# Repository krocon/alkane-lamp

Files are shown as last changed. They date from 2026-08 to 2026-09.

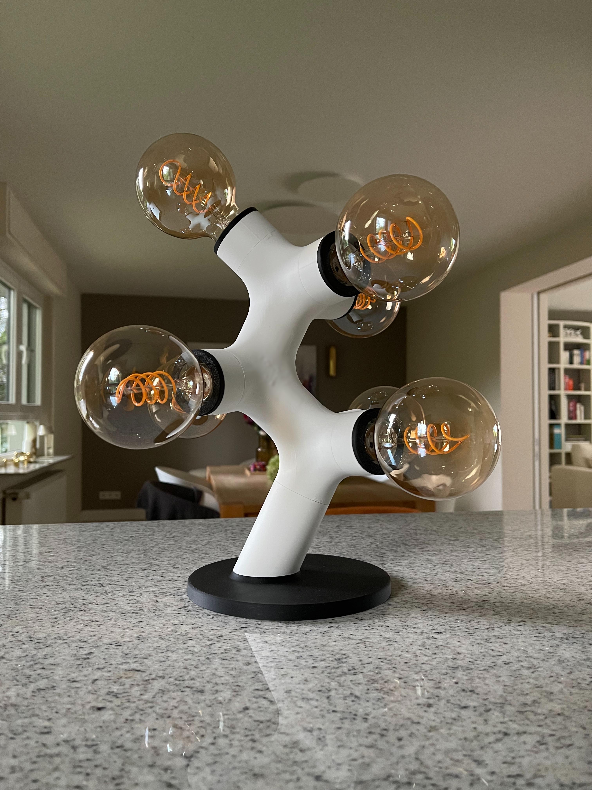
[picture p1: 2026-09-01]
picture/lamp-02.jpg

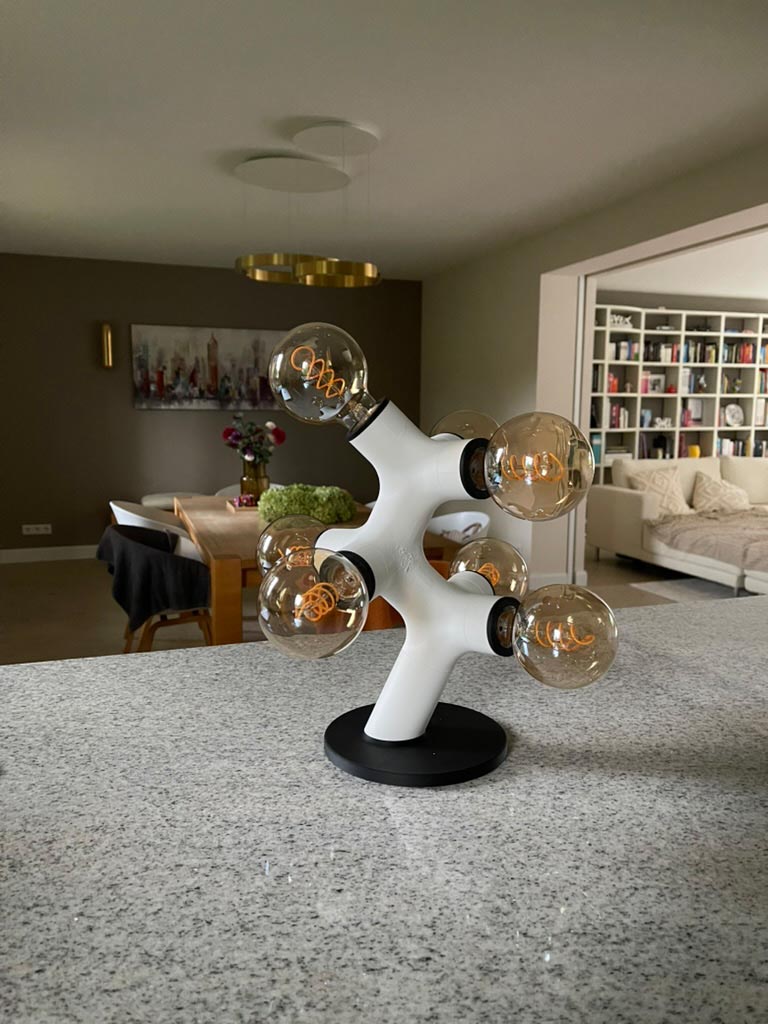
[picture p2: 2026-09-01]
picture/lamp-01.jpg

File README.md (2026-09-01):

# The Carbon Chain Chandelier

## The Alkane Modular Lamp System — Propane (C₃H₈) Edition

### A Scientifically Accurate, Modular Molecular Lighting System for 3D Printing






---

## Overview

Welcome to **The Carbon Chain Chandelier & Alkane Lamp System** — where organic chemistry meets modern Scandinavian sculptural lighting.

Inspired by iconic designer fixtures and molecular geometry, this project brings the fundamental building blocks of organic matter to life. Instead of arbitrary decorative shapes, every node, angle, and connection in this lamp is derived from **real covalent bonding geometry** (sp³ hybridization with the exact **109.47°** tetrahedral bond angle).

This first release features the **Propane (C₃H₈) Standing & Table Lamp**: a stunning 3-carbon backbone lamp with an integrated tilted base plate, hidden internal wiring channels, and modular socket connections.

It serves as the flagship model and the foundation for a **complete modular kit** — allowing you to expand from a single node to full organic chandeliers (**The Carbon Chain Chandelier** series), desk lamps, and sculptural floor installations.

---

## The Science Behind the Design

Alkanes are saturated hydrocarbons consisting entirely of single-bonded carbon and hydrogen atoms.

```
       H   H   H
       |   |   |
   H - C - C - C - H       Propane (C₃H₈)
       |   |   |
       H   H   H
```

### 1. Tetrahedral Carbon & sp³ Hybridization

In an alkane, each carbon atom undergoes sp³ hybridization, forming four equivalent covalent bonds directed toward the vertices of a regular tetrahedron. The mathematical bond angle is:

**θ = arccos(-1/3) ≈ 109.47°**

Every node in this lamp model strictly adheres to this 109.47° angle, giving it a natural, mathematically harmonious silhouette.

### 2. Staggered (Anti / Gauche) Conformation

Due to free rotation around the carbon-carbon (C-C) single σ-bonds, alkane chains naturally settle into a **staggered conformation**. This minimizes steric clash and torsional strain (Pitzer strain), resulting in the characteristic organic **zigzag backbone**. The Propane Lamp captures this exact 3D zigzag configuration in a self-balancing, visually captivating standing posture.

---

## Features & Highlights

- **True Modular Architecture:** Interchangeable tetrahedral carbon nodes, connector sleeves, weighted base plates, and socket adapters.
- **Internal Cable Routing:** Generous continuous hollow internal bores (Ø 43 mm) and an integrated base plate cable canal (Ø 7 mm with smooth chamfers) allow you to run standard electrical cables cleanly inside the lamp with zero exposed wires.
- **Self-Stabilizing Geometry:** The 160 mm base plate is tilted and counterbalanced to firmly support the 3-node propane structure with standard E27/E14 light fixtures and globes.
- **Optimized for FDM 3D Printing:** Designed to print with clean layer lines, robust wall thicknesses, and minimal/no unnecessary supports.
- **Standard Hardware Compatibility:** Designed for readily available E27 / E14 lamp sockets, Bambu LED Lamp Kits, or custom pendant cords.

---

## What's in the Kit?

The **Propane (C₃H₈) Starter Kit** includes all parametric parts required to build the complete standing lamp:

| Part Name | Description | Recommended Count |
| :--- | :--- | :---: |
| **`Node_1_Base`** | Tetrahedral Carbon Node 1 with integrated tilted foot stem | 1x |
| **`Node_2_Center`** | Tetrahedral Carbon Node 2 (central carbon backbone) | 1x |
| **`Node_3_Head`** | Tetrahedral Carbon Node 3 (top socket terminal) | 1x |
| **`Connector_Sleeves`** | Precision Ø 43 mm coupling sleeves with tolerance offset | 2x |
| **`Base_Plate_160mm`** | Heavy 160 mm circular base plate with rear cable outlet | 1x |
| **`Socket_Inlet_E27`** | Threaded / snap-in mount for standard E27 or E14 sockets | 1–3x (Optional) |
| **`M40_Locknut`** | Optional printed locknut for threaded modular joints | 1–3x |

> *Note: You can print the complete assembly in multi-piece modular format or as individual nodes depending on your build volume.*

---

## Bill of Materials (BOM) & Required Hardware

To complete the electrical build, you will need:

1. **Light Bulb Socket:**
   - 1x Standard **E27** (or **E14**) threaded socket with mounting collar / screw ring.
   - *Alternative:* Compatible with Bambu Lab LED Lamp Kit 001.

2. **Power Cord & Switch:**
   - 1x 2-conductor or 3-conductor lamp cord with inline switch and wall plug (cord diameter up to 6.5 mm).

3. **Light Bulb:**
   - 1x **LED Globe Bulb** (G80, G95, or G125 vintage filament LED recommended).
   - **IMPORTANT:** Use **LED bulbs only** (≤ 9W power consumption). Never use incandescent or halogen bulbs due to heat accumulation inside 3D printed plastics.

4. **Adhesive / Assembly (Optional):**
   - A few drops of Cyanoacrylate (Super Glue) or 2-part epoxy for locking connector sleeves if non-threaded slip fits are used.

---

## Recommended Print Settings

Optimized for **Bambu Lab X1-Carbon / P1S / A1** or any standard FDM printer with ≥ 180 × 180 × 180 mm build volume.

| Parameter | Recommended Setting | Rationale |
| :--- | :--- | :--- |
| **Filament Type** | **PLA Matte / PLA-CF / PETG** | PLA Matte gives a premium designer ceramic look; PETG offers higher thermal resistance. |
| **Layer Height** | **0.16 mm – 0.20 mm** | 0.16 mm provides ultra-smooth curves on tetrahedral fillets. |
| **Wall Loops (Perimeters)** | **4 – 5 Walls** | Crucial for structural rigidity, thread strength, and clean overhangs. |
| **Infill** | **15% – 25% Gyroid** | High torsional resistance and zero resonance. |
| **Base Plate Infill** | **40% – 60% Infill** | Adds weight to the lower base plate for maximum stability. |
| **Supports** | **Tree Supports (Auto / Organic)** | Only needed for downward steep overhangs on certain arm angles. Base and sleeves print support-free. |
| **Brim** | **Outer brim only (5 mm)** | Recommended for tall narrow node orientations. |

---

## Step-by-Step Assembly Guide

```
[Base Plate] ──► [Node 1 + Foot] ──► [Connector Pipe] ──► [Node 2] ──► [Connector Pipe] ──► [Node 3] ──► [E27 Socket + Bulb]
      │                                                                                                    ▲
      └──────────────────────── Internal Cable Routing (7 mm Bore) ────────────────────────────────────────┘
```

1. **Cable Pre-Routing:**
   - Thread your lamp cable from the bottom/rear cable exit hole through the channel in the **Base Plate**.
   - Feed the cable upwards through the hollow leg of **Node 1**.

2. **Backbone Assembly:**
   - Insert the **Connector Sleeve** between Node 1 and Node 2. Guide the cable through the center.
   - Attach Node 3 using the second connector sleeve. Ensure all nodes align with their tetrahedral indexing keys.

3. **Socket Wiring:**
   - Strip the wire ends (5 mm) and connect them firmly to your E27/E14 socket terminals.
   - Seat the socket into the top terminal of **Node 3** and secure it using the socket collar or threaded insert.

4. **Base Plate Securing:**
   - If using the split-plate model, insert the foot into the base plate socket and secure with glue or the locknut.
   - Apply self-adhesive rubber/felt pads underneath the base plate to protect your desk/floor.

5. **Install Bulb & Test:**
   - Screw in your favorite LED globe bulb.
   - Plug into the wall outlet and switch on!

---

## Safety & Electrical Disclaimer

> **Electrical Safety Notice:**
>
> - Working with mains voltage (110V / 230V) requires proper care. If you are not familiar with electrical wiring, purchase a pre-assembled lamp cord set (cord + inline switch + pre-wired socket) or consult a certified electrician.
> - **Only use LED bulbs (maximum 9W).** Traditional incandescent bulbs produce excessive heat that can deform PLA/PETG prints.
> - Ensure no bare copper wire touches printed parts and that proper strain relief is applied.

---

## Video Series & Future Roadmap

We are launching a dedicated video series showcasing:

- **Full Assembly & Wiring Walkthrough:** Step-by-step tutorial from slicing to glowing finish.
- **Fusion 360 Parametric Deep Dive:** How to model complex 109.47° multi-axis tetrahedral intersections using TypeScript and Fusion API.
- **Modular Expansions & Custom Rigs:** How to create your own organic configurations.

### The Alkane System Roadmap

- [x] **Propane (C₃H₈)** — Flagship 3-Node Standing / Table Lamp *(Current)*
- [ ] **Methane (CH₄)** — Minimalist Single-Node Ambient Desk Lamp
- [ ] **Ethane (C₂H₆)** — Dual-Node Linear Sconce / Bedside Lamp
- [ ] **Butane (C₄H₁₀) & Iso-Butane** — 4-Node Asymmetric Floor Sculpture & Branched Chandelier
- [ ] **The Alkane Chandelier Collection** — Ceiling-mounted suspended organic molecular lighting fixtures with multiple globes
- [ ] **Parametric Customizer / Online Generator** — Generate custom (CₙH₂ₙ₊₂) chain configurations!

---

## Share Your Makes & Feedback

If you build this lamp, please post your **Makes**, rate the profile on **MakerWorld**, and share which alkane molecule you'd like to see next!

- Tag your prints with `#AlkaneLamp` `#CarbonChainChandelier` `#MakerWorld`.
- Feel free to submit remixes, custom lamp shades, and adapter collars for different socket standards!

---

*Designed with precision in Autodesk Fusion 360. Parametric generator scripts and CAD files available in this repository.*

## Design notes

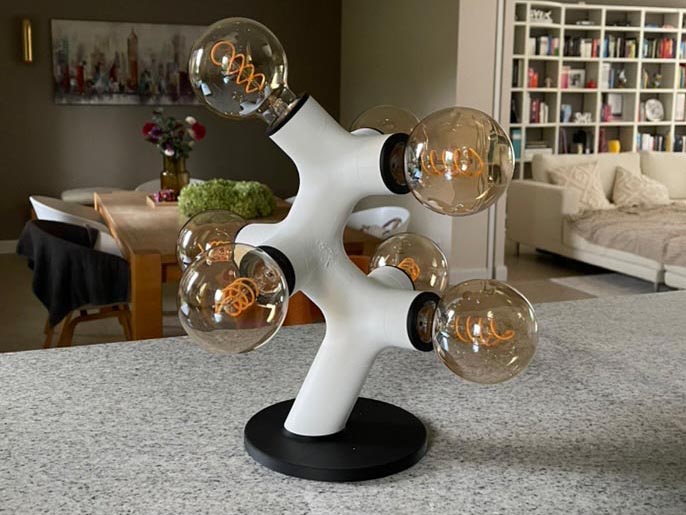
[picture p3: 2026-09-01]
picture/lamp-4_3.jpg

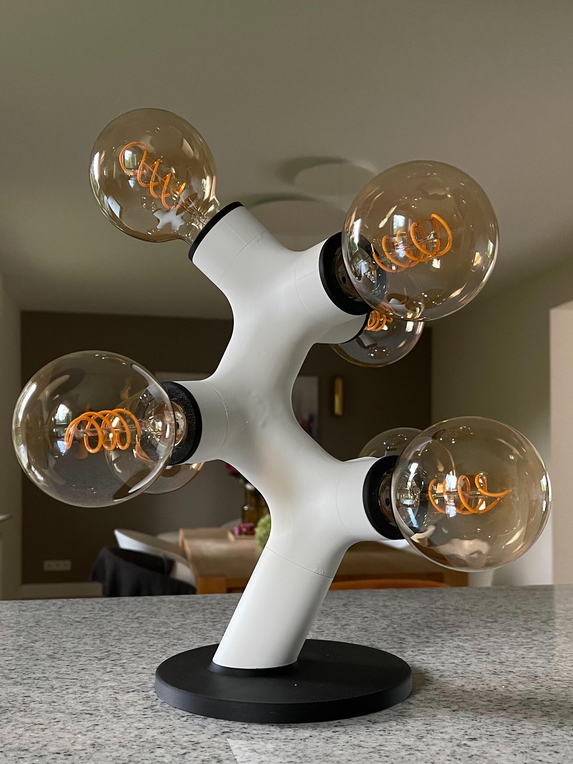
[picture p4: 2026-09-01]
picture/lamp-3_4.jpg

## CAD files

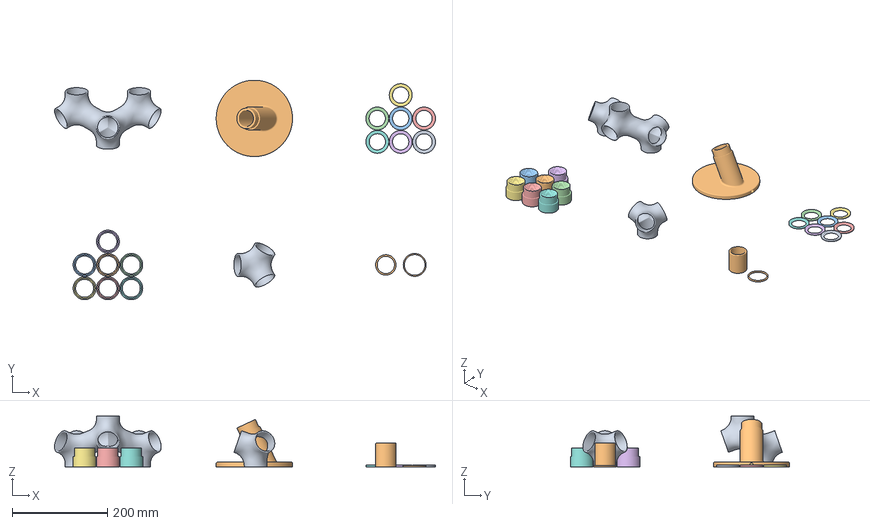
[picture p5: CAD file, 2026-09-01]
fusion/model/alkane-lamp-complete.3mf
798.8 x 460.2 x 106.7 mm
alkane-lamp-3x-nodes v1
alkane-lamp-plate-v5 v2
alkane-lamp-thread-m40x2_5-counternut v2 x 7
alkane-lamp-thread-inlet-m40x2_5 v2 x 7
alkane-lamp-node-v5 v5
alkane-lamp-connector-pipe-43mm v4

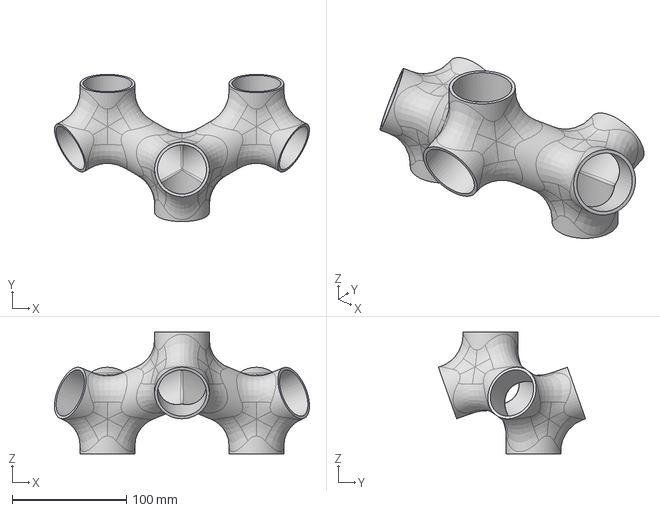
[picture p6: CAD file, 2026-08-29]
fusion/model/alkane-lamp-3x-nodes.step
223.6 x 129.1 x 106.7 mm

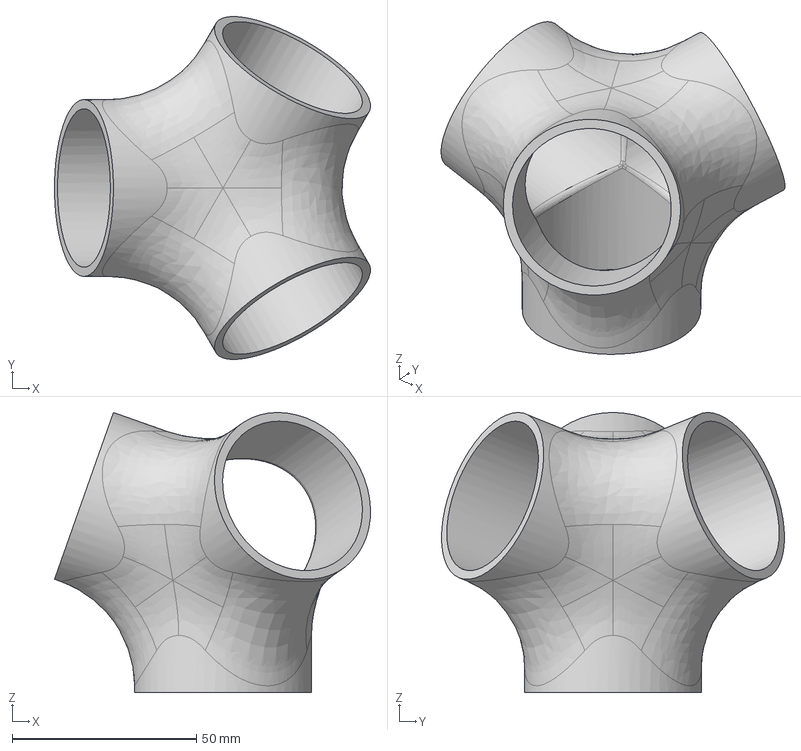
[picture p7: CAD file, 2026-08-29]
fusion/model/alkane-lamp-node-v5.step
85.7 x 93.0 x 76.0 mm

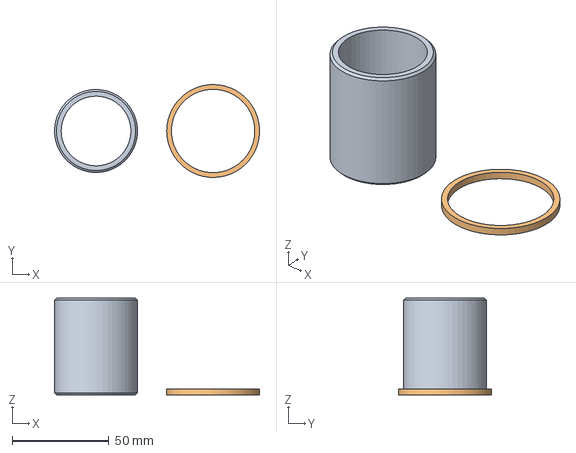
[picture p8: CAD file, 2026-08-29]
fusion/model/alkane-lamp-connector-pipe-43mm.step
105.9 x 48.0 x 50.0 mm

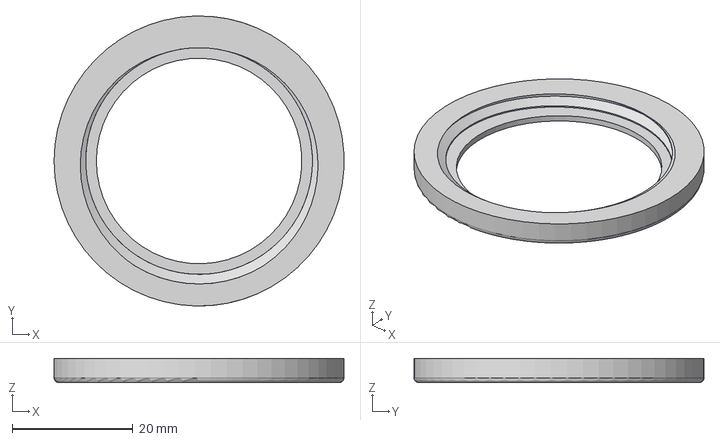
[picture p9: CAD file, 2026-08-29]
fusion/model/alkane-lamp-thread-m40x2_5-counternut.step
48.0 x 48.0 x 4.00 mm

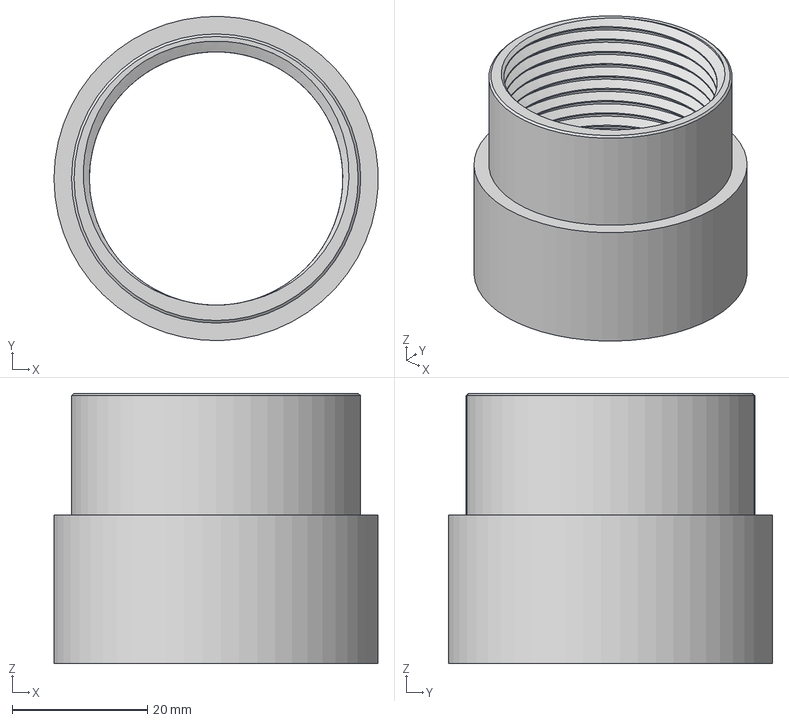
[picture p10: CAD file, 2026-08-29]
fusion/model/alkane-lamp-thread-inlet-m40x2_5.step
48.0 x 48.0 x 40.0 mm

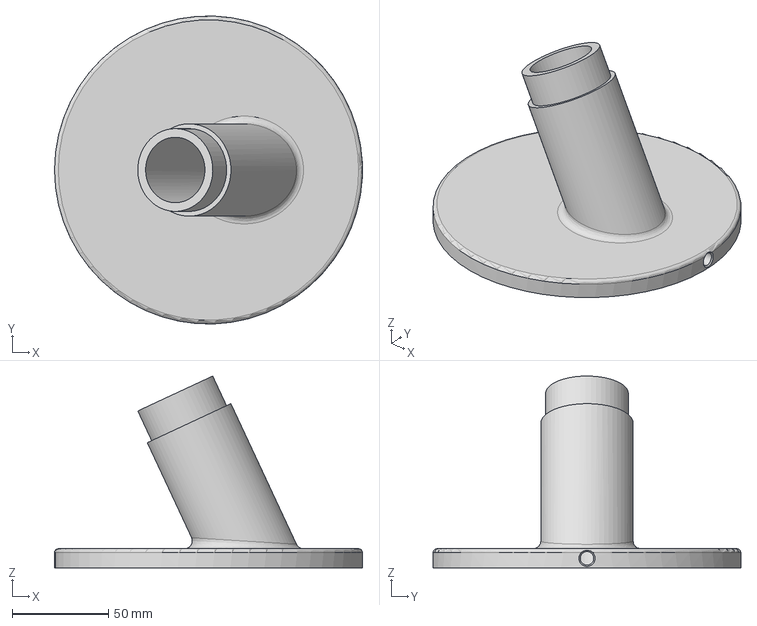
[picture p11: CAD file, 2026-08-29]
fusion/model/alkane-lamp-plate-v5.step
160.0 x 159.9 x 99.7 mm

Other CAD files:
fusion/model/alkane-lamp-plate-v5-2-colors.3mf
fusion/model/alkane-lamp-3x-nodes.3mf
fusion/model/alkane-lamp-3x-nodes.f3d
fusion/model/alkane-lamp-connector-pipe-43mm.3mf
fusion/model/alkane-lamp-connector-pipe-43mm.f3d
fusion/model/alkane-lamp-node-v5.f3d
fusion/model/alkane-lamp-plate-v5.f3d
fusion/model/alkane-lamp-thread-inlet-m40x2_5.f3d
fusion/model/alkane-lamp-thread-m40x2_5-counternut.3mf
fusion/model/alkane-lamp-thread-m40x2_5-counternut.f3d

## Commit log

2026-08-16 Add simple-leg.3mf file to project
    [simple-leg.3mf]
2026-08-16 Add base-plate.step file to project
    [base-plate.f3d, base-plate.step, base-plate.stl]
2026-08-17 Add al-base-plate.ts
    [simple-leg.3mf]
2026-08-17 Refactor al-base-plate.ts: Replace base plate generation with tetrapod creation logic
2026-08-17 Refactor al-base-plate.ts: Replace tetrapod logic with modular base plate and leg creation functions
2026-08-17 Refactor al-base-plate.ts: Apply consistent spacing, improve error handling, and streamline feature generation strategies
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2026-08-17 Add createBottomCableChannel: Generate sinusoidal cable channel with strain relief holes in al-base-plate.ts
2026-08-17 Add al-base-plate.step: Include STEP geometry file for base plate design
    [al-base-plate.f3d, al-base-plate.step]
2026-08-17 Add al-node-rounded: Introduce new script for creating rounded tetrapod joints in Fusion 360
2026-08-17 Refactor al-node-rounded: Finalize Tetrapod creation script with rounded joints, arm steps, and center holes
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2026-08-17 Add node-rounded.step: Include STEP file for rounded tetrapod design geometry
    [node-rounded.3mf, node-rounded.f3d, node-rounded.step]
2026-08-18 Adjust legInnerDiameter value to 40.025mm in simple-leg and leg-with-thread scripts; add node-rounded readme file
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2026-08-18 Add al-node-no-legs-not-rounded.step: Include STEP file for tetrapod design without legs or rounded edges
    [al-node-no-legs-not-rounded.f3d, al-node-no-legs-not-rounded.step]
2026-08-18 Rename and restructure node-no-legs-not-rounded files; add 3MF and G-code outputs
    [node-no-legs-not-rounded.3mf, node-no-legs-not-rounded.f3d, node-no-legs-not-rounded.gcode.3mf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]
2026-08-19 Add AGENTS.md for guidelines and best practices; include leg-with-thread-40025.step geometry file
    [leg-with-thread-40025.3mf, leg-with-thread-40025.f3d, leg-with-thread-40025.step]
2026-08-19 Update node-no-legs-not-rounded STEP file: replace outdated geometry and metadata with revised definitions
    [node-no-legs-not-rounded.f3d, node-no-legs-not-rounded.step]
2026-08-19 Centralize TypeScript configurations with shared `tsconfig.json`; update script-specific configs to use references. Add `package.json` and introduce TypeScript dependency for build and type-checking.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
2026-08-19 Update base-plate: adjust groove and tab dimensions for refined fit; increase radial clearance; add fillet to reduce edge artifacts
2026-08-19 Add al-base-plate-deckel STEP file: include geometric and material definitions for automotive design
    [al-base-plate-base.f3d, al-base-plate-base.step, al-base-plate-deckel.f3d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]
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2026-08-21 Add base-plate-simple-cable-hole STEP file: define geometric and material properties for automotive design.
    [al-base_plate-base.3mf, al-base_plate-deckel.3mf, al-base_plate.3mf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]
2026-08-21 Adjust base-plate-simple-cable-hole: increase cable diameter to 3mm and update STEP file geometry and properties accordingly.
    [base-plate-simple-cable-hole.f3d, base-plate-simple-cable-hole.step, node-rounded.3mf]
2026-08-21 Add complete.ts Tetrapod script: implement Fusion 360 geometry generation for Alkane Lamp node, including long/short arms, inner sphere cutout, thread, and bore features; configure TypeScript, script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
2026-08-21 Refactor complete.ts Tetrapod script: standardize short arm usage, introduce third node generation with precise positioning and spatial alignment, and streamline hole creation logic.
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2026-08-22 Refactor and update complete.ts: move base plate edge fillet logic to the final step, improve edge detection, and handle fallback for edge filleting failures.
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2026-08-22 Add STEP file export for complete geometry
    [complete.3mf, complete.f3d, complete.step]
2026-08-23 Update offset value in complete.ts: change from -0.1mm to -0.15mm for face offset adjustment
    [complete.3mf]
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2026-08-23 Update default and replace `holeDiameter` with `footLegBoreDiameter` in complete-v2.ts: adjust parameters, sketches, and related logic for Z-leg bore diameter.
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2026-08-24 Initial implementation of `complete-v2.js`: add main assembly logic for creating a complete tetrapod design with parameters, assembly steps, and advanced geometry handling for nodes, arms, and connec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
    [complete-bottom.f3d, complete-bottom.step, complete-top.f3d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]
2026-08-25 Update `complete-top.step`: modify timestamp and adjust geometry representation for enhanced alignment and improved solid assembly matching.
    [complete-bottom.step, complete-top.step, complete-v2-connector-pipe.f3d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]
2026-08-25 Add `thread-inlet-m40x2_5-clearance-0_15` script: initial implementation with parameters, script manifest, and SVG icon for Fusion 360 inlet design.
2026-08-25 Update `thread-inlet-m40x2_5-clearance-0_15.ts`: implement full inlet creation logic, including threading, stopper geometry, ribbing, and chamfering
    [complete-top.3mf, complete-v2-connector-pipe.3mf, thread-inlet-m40x2.5-clearance-0.15.3mf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]
2026-08-25 Update `thread-inlet-m40x2_5-clearance-0_15` script: adjust thread clearance to -0.25mm, add pipe clearance parameter (-0.2mm), and update effective outer diameter calculations, script documentation,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
2026-08-25 Remove `thread-inlet-m40x2.5-clearance-0.15.step` file: deprecated and no longer required in current design.
    [thread-inlet-m40x2.5-clearance-0.15.3mf, thread-inlet-m40x2.5-clearance-0.15.step, thread-inlet-m40x2_5.3mf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]
2026-08-26 Add `thread-m40x2_5-counternut` script: initial implementation for generating M40x2.5 locknut with configurable thread clearance, integrated end disc, and optimized geometry for FDM 3D printing; incl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
    [thread-m40x2_5-counternut.3mf, thread-m40x2_5-counternut.f3d, thread-m40x2_5-counternut.step]
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2026-08-26 Add `complete-v3.step`: initial STEP file for `complete-v3` geometry, including updated solid representations, connector pipes, and enhanced geometric alignment.
    [complete-v3.f3d, complete-v3.step]
2026-08-26 Add `complete-v3.3mf`: initial 3D manufacturing file for `complete-v3` geometry including updated model representation.
    [complete-v3.3mf]
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2026-08-28 Update `thread-inlet-m40x2_5.ts` and model: adjust stopper and pipe parameters (diameter/length).
    [thread-inlet-m40x2_5.3mf]
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2026-08-28 Remove `al-base-plate` script and STEP model: deprecated script and associated assets.
    [al-base-plate-base.f3d, al-base-plate-base.step, al-base-plate-deckel.f3d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]
2026-08-28 Update `thread-m40x2_5-counternut`: adjust outer diameter to 48mm and update associated calculations; add corresponding STEP model.
    [alkane-lamp-thread-m40x2_5-counternut.f3d, alkane-lamp-thread-m40x2_5-counternut.step]
2026-08-28 Add `alkane-lamp-connector-pipe-43mm` script: implement Fusion 360 script for parameterized connector pipe generation (AD=42.8mm, ID=36mm, L=40mm, chamfer=1mm); include STEP and F3D models, manifest,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
    [alkane-lamp-connector-pipe-43mm.f3d, alkane-lamp-connector-pipe-43mm.step, alkane-lamp-plate-v5.f3d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]
2026-08-29 Add `alkane-lamp-connector-pipe-43mm` models: include `connector-pipe-43mm.3mf`, `plate-v5-2-colors.3mf`, and `thread-m40x2_5-counternut.3mf`
    [alkane-lamp-connector-pipe-43mm.3mf, alkane-lamp-plate-v5-2-colors.3mf, alkane-lamp-thread-m40x2_5-counternut.3mf]
2026-08-29 Update `alkane-lamp-connector-pipe-43mm` script: add centered stop ring (OD=48mm, L=3mm), adjust overall pipe length to 50mm, refine tolerance parameters, and update chamfer logic; regenerate associa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
    [alkane-lamp-connector-pipe-43mm.3mf, alkane-lamp-connector-pipe-43mm.step, alkane-lamp-thread-m40x2_5-counternut.3mf]
2026-08-29 Refactor `alkane-lamp-connector-pipe-43mm` script: add optional separate or integrated stop ring functionality, update parameters (e.g., ring clearance/tolerance), adjust result structure, and enhanc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
    [alkane-lamp-connector-pipe-43mm.f3d, alkane-lamp-connector-pipe-43mm.step, alkane-lamp-node-v5.f3d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]
2026-08-29 Add `alkane-lamp-3x-nodes` script: implement Fusion 360 script to generate a parameterized 3-node alkane lamp structure with tetrapod geometry, including TypeScript configuration, comprehensive node 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
    [alkane-lamp-3x-nodes.3mf, alkane-lamp-3x-nodes.f3d, alkane-lamp-3x-nodes.step]
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2026-09-01 Revise README.md: improve formatting, update scientific notation (e.g., sp³ hybridization, bond angles), and enhance content clarity; add visual assets and 3MF model for the "Propane (C₃H₈) Lamp."
    [alkane-lamp-complete.3mf]

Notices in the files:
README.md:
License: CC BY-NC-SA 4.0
